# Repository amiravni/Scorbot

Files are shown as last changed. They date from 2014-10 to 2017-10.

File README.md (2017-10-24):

This is my work of building a Scorbot ER-V Controller with an arduino MEGA and drivers.

The project description is here: http://whatimade.today/geekcon-xii-scorbot-learns-to-draw/

Files and Folders consist of:

scorbotCOMcontrol - Most updated code, can get 6 encoder values and moves towards them

python - Python code for drawing images with scorbot

files - Some modified files to use with the python code

Eagle - Arduino mega shield design for scorbot

scorbotShieldTest - Shield Test...

Pins - Scorbot 50 Pins Data

ER3-Manual - Scorbot Manual

scorbotOldTestCode - My early work on scorbot, described here: http://www.whatimade.today/my-name-is-scorbot/

* Encoder_Scorbot - CPP code for encoders, taken and modified from  https://github.com/frodofski/Encoder_Polling_V2

* ScorbotCmd - The final code for controlling the Scorbot (Under Construction)

* ScorbotTest - Test code for Motors, Encoders and MicroSwitches

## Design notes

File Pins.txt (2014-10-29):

#/PIN/MOTOR

1,P0,2,         ,,,             34,P0,G
2,P0,1,         18,P0,5,        35,P0,4
3,P1,5,         19,P1,G,        36,P0,3
4,P1,3,         20,P1,4,        37,,
5,P1,1,         21,P1,2,        38,,
6,MS,5,         22,MS,G(NO),    39,,
7,MS,2,         23,MS,1,        40,,
8,MS,4,         24,MS,3,        41,,
9,LED,5,        25,LED,G,       42,,
10,LED,3,       26,LED,4,       43,,
11,LED,1,       27,LED,2,       44,,
12,M2,G,        28,GND,G,       45,M1,G
13,M2,5,        29,GND,5,       46,M1,5
14,M2,4,        30,GND,4,       47,M1,4
15,M2,3,        31,GND,3,       48,M1,3
16,M2,2,        32,GND,2,       49,M1,2
17,M2,1,        33,GND,1,       50,M1,1

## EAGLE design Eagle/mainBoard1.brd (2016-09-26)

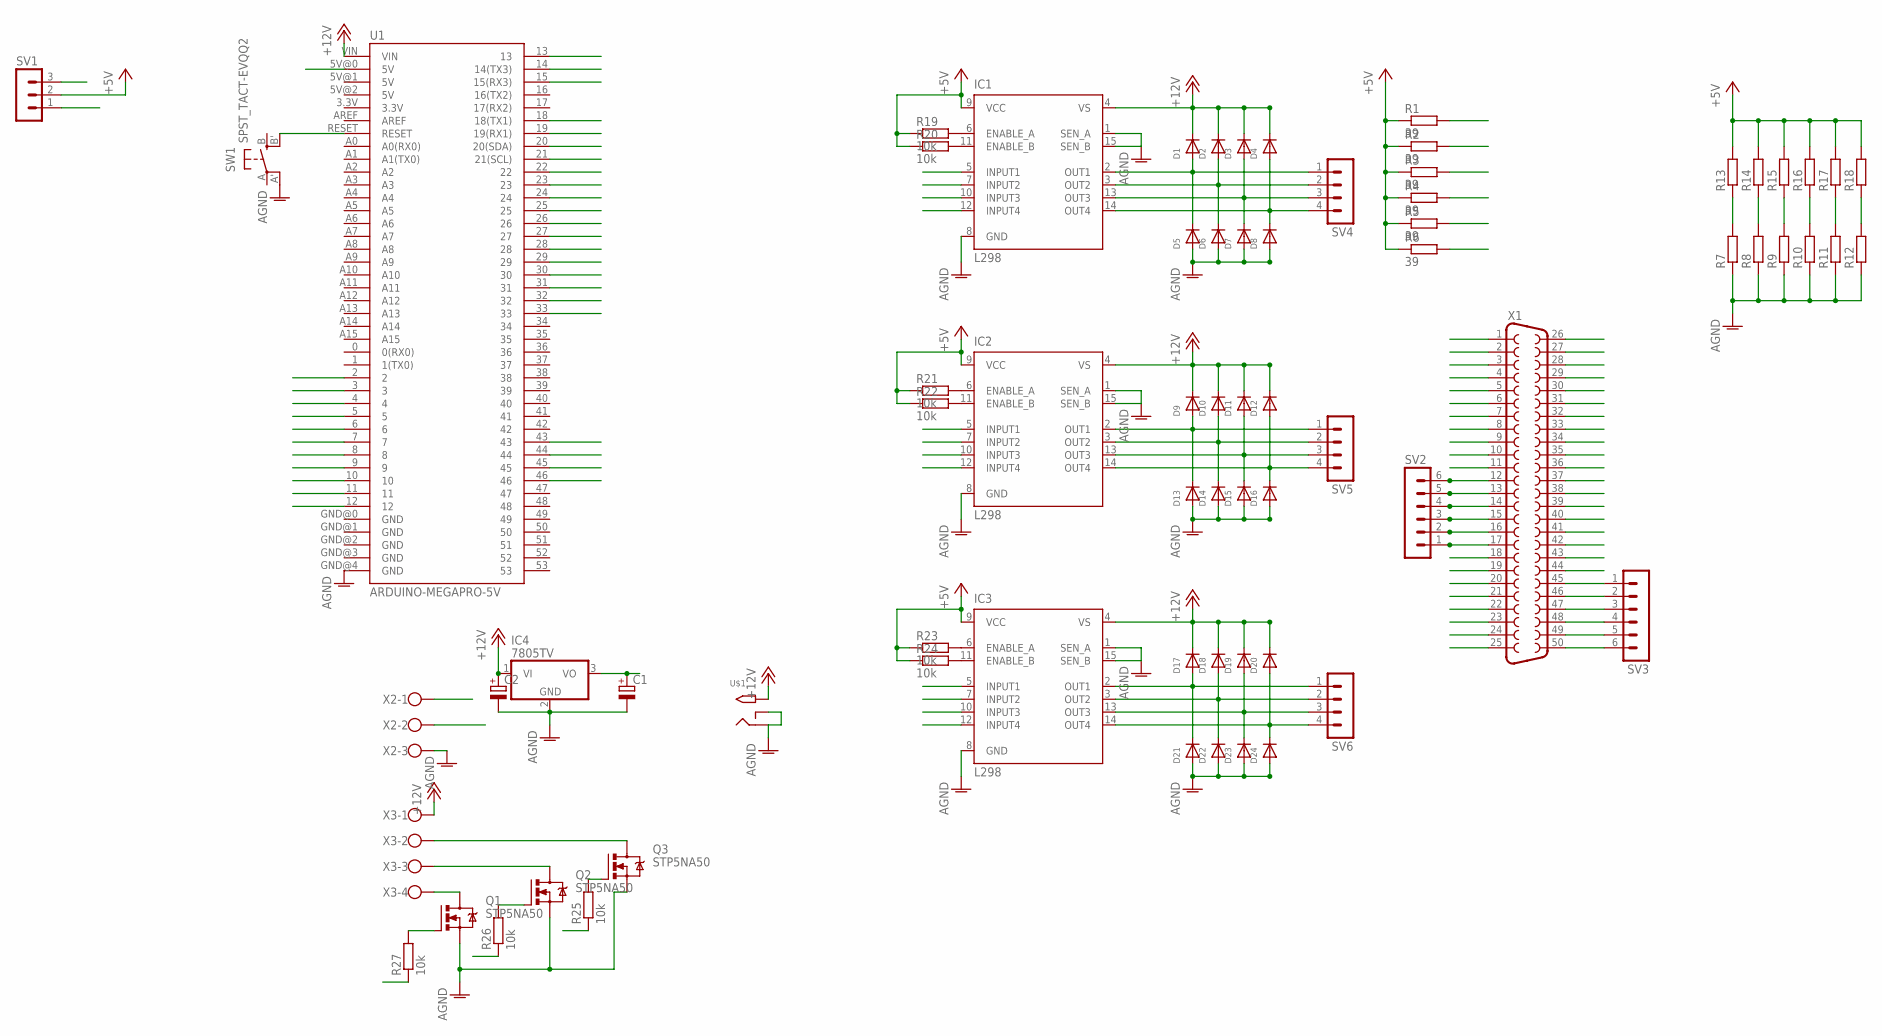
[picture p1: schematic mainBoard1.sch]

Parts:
C1, C2: CPOL-EUE2,5-6E; E2,5-6E
D1, D2, D3, D4, D5, D6, D7, D8, D9, D10, D11, D12, D13, D14, D15, D16, D17, D18, D19, D20, D21, D22, D23, D24: DIODESOD-323F; SOD-323F
IC1, IC2, IC3: L298; MULTIWATT-15
IC4: 7805TV; TO220V
Q1, Q2, Q3: STP5NA50; TO220BV
R1, R2, R3, R4, R5, R6: 39; 0207/10
R7, R8, R9, R10, R11, R12, R13, R14, R15, R16, R17, R18: R0207/10; 0207/10
R19, R20, R21, R22, R23, R24, R25, R26, R27: 10k; R0805
SV1: MA03-1
SV2, SV3: MA06-1
SV4, SV5, SV6: MA04-1
SW1: SPST_TACT-EVQQ2; EVQ-Q2
U1: ARDUINO-MEGAPRO-5V; ARDUINO_MEGA-PRO-5V
U$1: 2.1MMJACKTHM; PJ-102A
X1: F50VP
X2: W237-103
X3: W237-4

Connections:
5V_ARD: SV1.3, U1.5V@0 (5V)
5V_REG: C1.+, IC4.3 (VO), SV1.1, X2.1
+5V: IC1.9 (VCC), IC2.9 (VCC), IC3.9 (VCC), R1.1, R2.1, R3.1, R4.1, R5.1, R6.1, R13.2, R14.2, R15.2, R16.2, R17.2, R18.2, R19.1, R20.1, R21.1, R22.1, R23.1, R24.1, SV1.2
+12V: C2.+, D1.C, D2.C, D3.C, D4.C, D9.C, D10.C, D11.C, D12.C, D17.C, D18.C, D19.C, D20.C, IC1.4 (VS), IC2.4 (VS), IC3.4 (VS), IC4.1 (VI), U1.VIN, U$1.TIP, X3.1
AGND: C1.-, C2.-, D5.A, D6.A, D7.A, D8.A, D13.A, D14.A, D15.A, D16.A, D21.A, D22.A, D23.A, D24.A, IC1.1 (SEN_A), IC1.8 (GND), IC1.15 (SEN_B), IC2.1 (SEN_A), IC2.8 (GND), IC2.15 (SEN_B), IC3.1 (SEN_A), IC3.8 (GND), IC3.15 (SEN_B), IC4.2 (GND), Q1.S, Q2.S, Q3.S, R7.1, R8.1, R9.1, R10.1, R11.1, R12.1, SW1.A' (P1), U1.GND@4 (GND), U$1.RING, U$1.RING_SW, X1.28, X1.29, X1.30, X1.31, X1.32, X1.33, X2.3
LED_0: R1.2, X1.11
LED_1: R2.2, X1.27
LED_2: R3.2, X1.10
LED_3: R4.2, X1.26
LED_4: R5.2, X1.9
LED_5: R6.2, X1.25
LED_B: R27.1, U1.46
LED_DATA: U1.43, X2.2
LED_G: R26.1, U1.45
LED_R: R25.1, U1.44
M1_0: D1.A, D5.C, IC1.2 (OUT1), SV3.6, SV4.1, X1.50
M1_0_IN: IC1.5 (INPUT1), U1.14 (14(TX3))
M1_1: D3.A, D7.C, IC1.13 (OUT3), SV3.5, SV4.3, X1.49
M1_1_IN: IC1.10 (INPUT3), U1.4
M1_2: D9.A, D13.C, IC2.2 (OUT1), SV3.4, SV5.1, X1.48
M1_2_IN: IC2.5 (INPUT1), U1.6
M1_3: D11.A, D15.C, IC2.13 (OUT3), SV3.3, SV5.3, X1.47
M1_3_IN: IC2.10 (INPUT3), U1.8
M1_4: D17.A, D21.C, IC3.2 (OUT1), SV3.2, SV6.1, X1.46
M1_4_IN: IC3.5 (INPUT1), U1.10
M1_5: D19.A, D23.C, IC3.13 (OUT3), SV3.1, SV6.3, X1.45
M1_5_IN: IC3.10 (INPUT3), U1.12
M2_0: D2.A, D6.C, IC1.3 (OUT2), SV2.1, SV4.2, X1.17
M2_0_IN: IC1.7 (INPUT2), U1.15 (15(RX3))
M2_1: D4.A, D8.C, IC1.14 (OUT4), SV2.2, SV4.4, X1.16
M2_1_IN: IC1.12 (INPUT4), U1.5
M2_2: D10.A, D14.C, IC2.3 (OUT2), SV2.3, SV5.2, X1.15
M2_2_IN: IC2.7 (INPUT2), U1.7
M2_3: D12.A, D16.C, IC2.14 (OUT4), SV2.4, SV5.4, X1.14
M2_3_IN: IC2.12 (INPUT4), U1.9
M2_4: D18.A, D22.C, IC3.3 (OUT2), SV2.5, SV6.2, X1.13
M2_4_IN: IC3.7 (INPUT2), U1.11
M2_5: D20.A, D24.C, IC3.14 (OUT4), SV2.6, SV6.4, X1.12
M2_5_IN: IC3.12 (INPUT4), U1.13
MS_0: R7.2, R13.1, U1.2, X1.23
MS_1: R8.2, R14.1, U1.3, X1.7
MS_2: R9.2, R15.1, U1.21 (21(SCL)), X1.24
MS_3: R10.2, R16.1, U1.20 (20(SDA)), X1.8
MS_4: R11.2, R17.1, U1.19 (19(RX1)), X1.6
MS_5: R12.2, R18.1, U1.18 (18(TX1)), X1.22
unnamed: Q1.D, X3.4
unnamed: Q3.D, X3.2
unnamed: Q2.D, X3.3
unnamed: IC1.6 (ENABLE_A), R19.2
unnamed: IC1.11 (ENABLE_B), R20.2
unnamed: Q3.G, R25.2
unnamed: Q2.G, R26.2
unnamed: Q1.G, R27.2
unnamed: IC2.6 (ENABLE_A), R21.2
unnamed: IC2.11 (ENABLE_B), R22.2
unnamed: IC3.6 (ENABLE_A), R23.2
unnamed: IC3.11 (ENABLE_B), R24.2
unnamed: SW1.B' (S1), U1.RESET
P0_0: U1.22, X1.2
P0_1: U1.24, X1.1
P0_2: U1.26, X1.36
P0_3: U1.28, X1.35
P0_4: U1.30, X1.18
P0_5: U1.32, X1.34
P1_0: U1.23, X1.5
P1_1: U1.25, X1.21
P1_2: U1.27, X1.4
P1_3: U1.29, X1.20
P1_4: U1.31, X1.3
P1_5: U1.33, X1.19

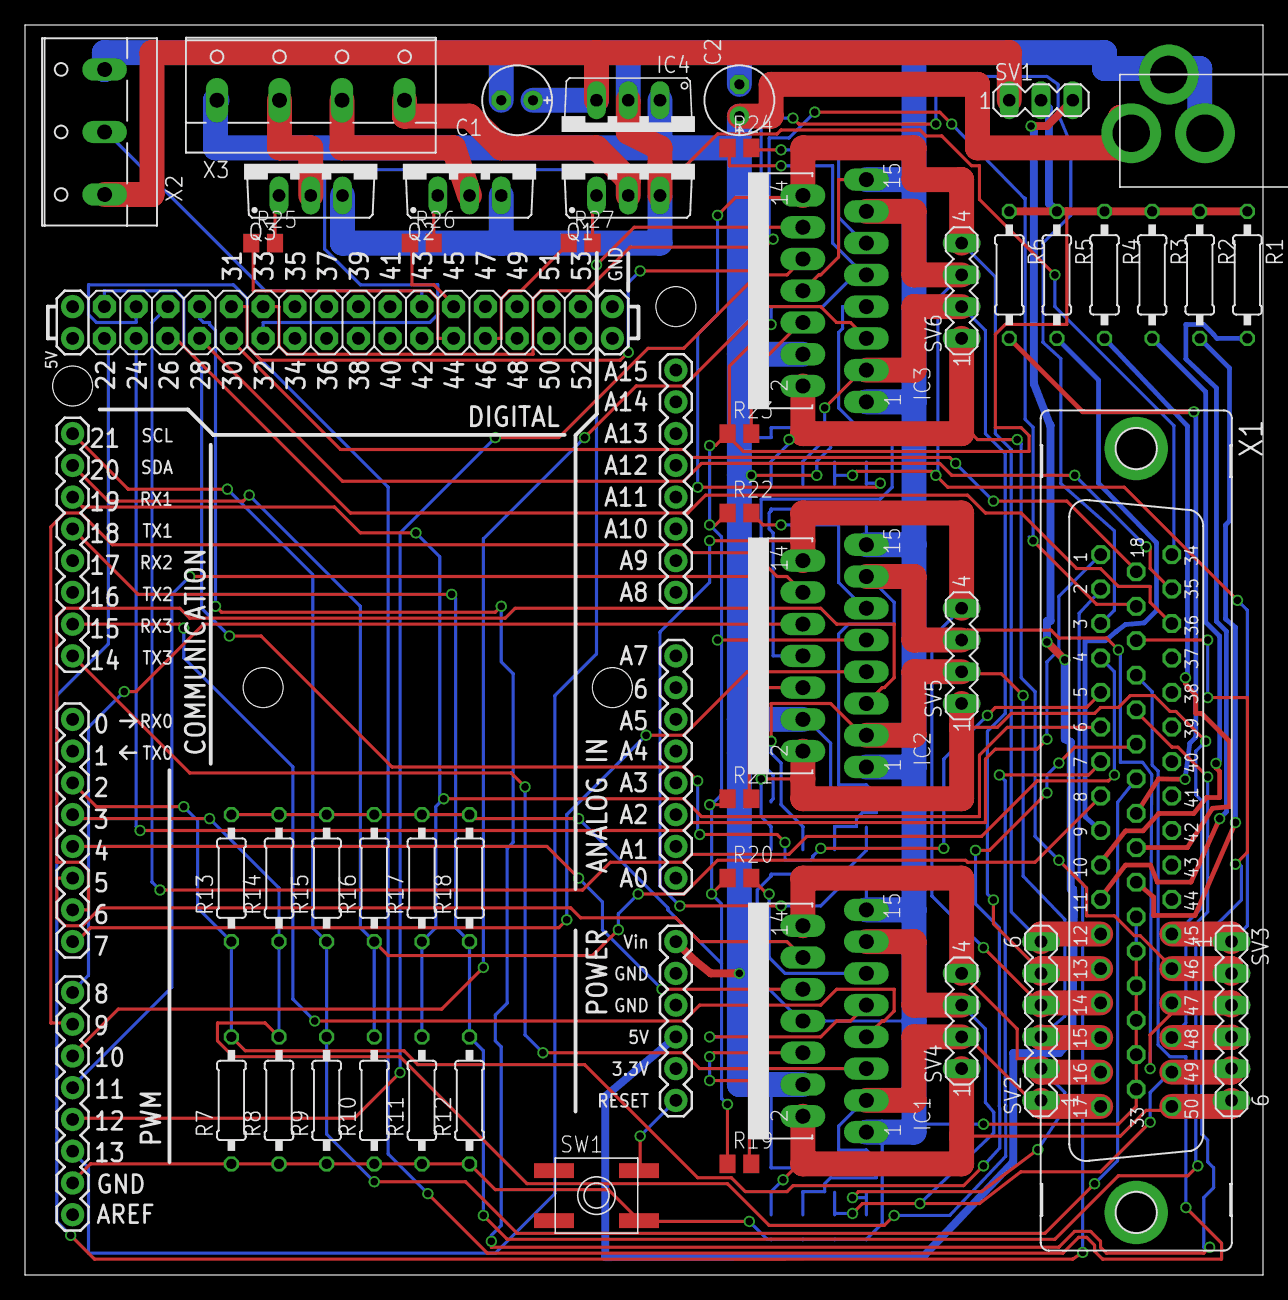
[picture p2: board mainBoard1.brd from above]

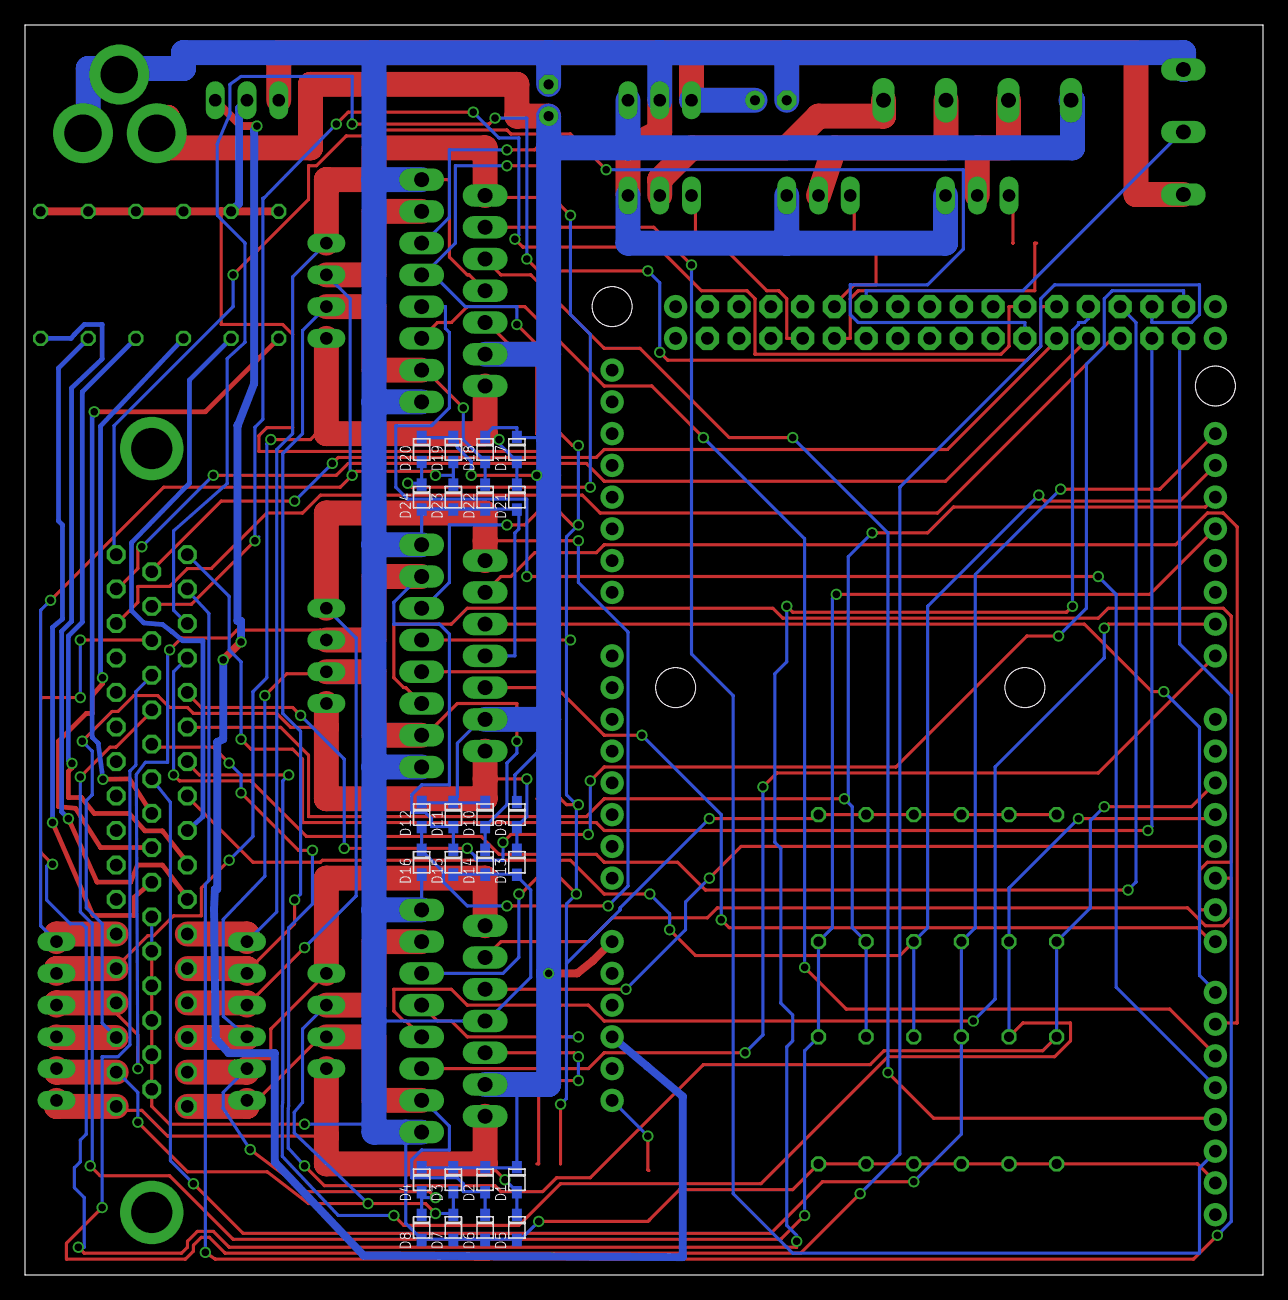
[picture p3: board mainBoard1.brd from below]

Board: 2 copper layers, 99.0 x 100.0 mm, 72 parts (24 on the bottom side), 70 nets.

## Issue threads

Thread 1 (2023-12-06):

comm control

ramonflores08, 2023-12-06:
Hello, I know this project was ages ago, but I was wondering if I could get some help getting my scorbot up and running. I will be getting the PCB next week, but I wanted to get a jump on the code. is there any way to get it to go to a certain coordinate just by communicating through serial instead of using the python scripts. I am terrible at python.

ramonflores08, 2023-12-06:
Lucky me I just got an email that the PCB will be here today. Way earlier than expected, but it will allow me more time to get this project up and running before the holidays.

I appreciate the reply and will do my best to do the conversion from Python to Arduino. I don't necessarily need XYZ coordinates though, so maybe I will just go with fixed coordinates for the time being.

My goal is to make this Scorbot into a bartender for the holidays.

ramonflores08, 2023-12-23:
https://github.com/amiravni/Scorbot/assets/7199615/a87f29c6-a5a7-44fb-8919-c1b9c3ae2dd2

I wanted to thank you for the amazing starting point and wanted to give you an update on my version in case you were interested. Maybe you still have that arm and want to give it some new life lol.

amiravni, 2023-12-29:
Thanks man! You just made my day with this video! When my kids grow up a bit more I'll go back to upgrade my project as well :)
I would be very happy to get the updated version and add it to the repository for everyone

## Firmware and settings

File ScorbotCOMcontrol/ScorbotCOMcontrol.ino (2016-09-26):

// NOTES:
// arm2 gets only negative values
// pitch gets only negative values

#define LEDPIN 49
#define TESTLED 1

#include "Encoder_Polling_V2.h"

#include <Adafruit_NeoPixel.h>
#ifdef __AVR__
  #include <avr/power.h>
#endif

#define PIN 43
Adafruit_NeoPixel strip = Adafruit_NeoPixel(55, PIN, NEO_GRB + NEO_KHZ800);

unsigned long timeStart;
volatile bool calibration = true;
// —————————————————————————  MicroSwitches
const int MS[6] = {
  2, 3, 21, 20, 19, 18
};
volatile boolean  MSpressed[6] = {
  0, 0, 0, 0, 0, 0
};
boolean initMTRCCW[6] = {false, false, true, false, true, true};

// —————————————————————————  Encoders
const int pin_P0[6] = {
  22, 24, 26, 28, 30, 32
};  // Encoder input pins
const int pin_P1[6] = {
  23, 25, 27, 29, 31, 33
};
int motors_current_state[6] = {
  0, 0, 0, 0, 0, 0
};
volatile short counter[6] = {
  0, 0, 0, 0, 0, 0
};
// —————————————————————————  Motors
//const int M1[6] = {
//  14,4,6,8,10,12};
//const int M2[6] = {
//  15,5,7,9,11,13};
const int M2[6] = {14, 4, 44, 8, 11, 12};
const int M1[6] = {15, 5, 7, 9, 10, 13};

const byte  headerChars[3] = {255, 254, 100};
const byte  headerInitChars[3] = {255, 254, 200};
const byte  headerPolyChars[3] = {255, 254, 150};
byte header[3] = {0, 0, 0};
short encoder_positions[6] = {0 , 0, 0, 0, 0, 0};
byte* encoder_position_ptr = (byte*)&encoder_positions;
short init_positions[6] = {0 , 0, 0, 0, 0, 0};
byte* init_position_ptr = (byte*)&init_positions;
short poly_positions[37];
byte* poly_position_ptr = (byte*)&poly_positions;
const int numOfCommandsPoly = 100;
int ptr = 0;

// ————————————————————————— Setup
void setup() {
  Serial.begin(9600);
  strip.begin();
  strip.show(); // Initialize all pixels to 'off'
  encoder_begin();  // Start the library
  for (int i = 0; i < 6; i++) {
    attach_encoder(i, pin_P0[i], pin_P1[i]);  // Attach an encoder to pins A and B
    pinMode(pin_P0[i], INPUT_PULLUP);
    pinMode(pin_P1[i], INPUT_PULLUP);
    pinMode(M1[i], OUTPUT);
    pinMode(M2[i], OUTPUT);
    motorST(M1[i], M2[i]);
    pinMode(MS[i], INPUT);
  }
  for (int i = 0; i < 5; i++) {
    Serial.print(MSpressed[i]);
  }
  Serial.println(MSpressed[6]);
  for (int iii = 0; iii < 37; iii++) {
    poly_positions[iii] = 0;
  }
  attachInterrupt(0, resetCounter0, FALLING);
  attachInterrupt(1, resetCounter1, FALLING);
  attachInterrupt(2, resetCounter2, FALLING);
  attachInterrupt(3, resetCounter3, FALLING);
  attachInterrupt(4, resetCounter4, FALLING);
  //attachInterrupt(5, resetCounter5, FALLING);
  pinMode(LEDPIN, OUTPUT);

  for (int i = 0; i < 5; i++) {
    Serial.print(MSpressed[i]);
  }
  Serial.println(MSpressed[6]);
 //rainbow(20);

  /*
    for (int i = 0; i < 5; i++) {
    Serial.print(MSpressed[i]);
    }
    Serial.println("");

    Serial.println("Current Counter:");

    for (int i = 0; i < 6 - 1; i++) {
    Serial.print(counter[i]);
    Serial.print("  ,  ");
    }
    Serial.println(counter[5]);

    Serial.println("Future Counter:");

    for (int i = 0; i < 6 - 1; i++) {
    Serial.print(encoder_positions[i]);
    Serial.print("  ,  ");
    }
    Serial.println(encoder_positions[5]);
  */
}

// ————————————————————————— MAIN



void loop() {
  short dir0[6] = {
    0, 0, 0, 0, 0, 0
  };
  ptr = 0;
  int point_or_poly = -1;
  bool print_encoders = 0;

  /// Serial read
  while (Serial.available() > 0)
  {
    header[0] = (byte)Serial.read();
    if (header[0] != headerChars[0]) {
      Serial.println("break0!");      
      break;
    }
    while (Serial.available() <= 0) {}
    header[1] =  (byte)Serial.read();
    if (header[1] != headerChars[1]) {
      Serial.println("break1!");      
      break;
    }

    while (Serial.available() <= 0) {}
    header[2] =  (byte)Serial.read();
    if (header[2] != headerChars[2] && header[2] != headerInitChars[2] && header[2] != headerPolyChars[2]) {
      Serial.println("break2!");
      break;
    }
    Serial.println("PASS!");
    if (header[2] == headerChars[2]) {
      point_or_poly = 0;
      while (ptr < 6 * sizeof(short)) {
        while (Serial.available() <= 0) {}
        encoder_position_ptr[ptr++] = (byte)Serial.read();  // ptr to byte array of 12, and then we get 6 shorts
      }

      if (encoder_positions[3] != encoder_positions[4]) {
        encoder_positions[4] = encoder_positions[3];
      }
      Serial.print("Srl: ");
      for (int i = 0; i < 5; i++) {
        Serial.print(encoder_positions[i]);
        Serial.print("  ,  ");
      }
      Serial.println(encoder_positions[5]);
      print_encoders = 1;

    }
    if (header[2] == headerInitChars[2]) {
      while (ptr < 6 * sizeof(short)) {
        while (Serial.available() <= 0) {}
        init_position_ptr[ptr++] = (byte)Serial.read();  // ptr to byte array of 12, and then we get 6 shorts
      }

      for ( int iii = 0; iii < 6 ; iii++) {
        if (init_positions[iii]) {
          initMTRCCW[iii] = true;
        }
        else {
          initMTRCCW[iii] = false;
        }
      }
      Serial.print("SrlHome: ");
      for (int i = 0; i < 5; i++) {
        encoder_positions[i] = 0;
        counter[i] = 0;
        Serial.print(init_positions[i]);
        Serial.print("  ,  ");
      }
      Serial.println(init_positions[5]);
      goHome();

      calibration = false;
    }
    if (header[2] == headerPolyChars[2]) {
      point_or_poly = 1;
      while (ptr < (6 * 6 + 1) * sizeof(short)) {
        while (Serial.available() <= 0) {}
        poly_position_ptr[ptr++] = (byte)Serial.read();  // ptr to byte array of 12, and then we get 6 shorts
        //Serial.print((int)poly_position_ptr[ptr - 1]);
        //Serial.print(",");
      }
      Serial.print("SrlPoly: ");
      for (int i = 0; i < 36; i++) {
        Serial.print(poly_position_ptr[i]);
        Serial.print("  ,  ");
      }
      Serial.println(poly_position_ptr[36]);
    }
  }

  int numOfCommands = 1;
  float dT = 0;
  if (point_or_poly == 1) {
    numOfCommands = numOfCommandsPoly;
    dT =  (float)poly_positions[36] / (float)numOfCommands;
    Serial.print("Srldt: ");
    Serial.println(dT);
  }
  if (point_or_poly == 0) numOfCommands = 1;


  for (int nnn = 0; nnn < numOfCommands; nnn++) {
    if (point_or_poly == 1) {
      for (int e = 0; e < 3; e++) {
        float newTime = dT * (float)nnn;
        float encoderTmp = 0;
        encoder_positions[e] = 0;
        for (int p = 0; p < 5; p++) {
          //encoder_positions[e] = (encoder_positions[e] + poly_position[ e*6 + p]/10 ) * newTime;
          encoderTmp = (encoderTmp + (float)poly_positions[ e * 6 + p] / 10.0 ) * newTime;
        }
        encoder_positions[e] = (short)floor(encoderTmp + (float)poly_positions[ e * 6 + 5] / 10.0);
      }
    }

    bool finish_movement_flag = 0;
    timeStart = millis();
    while (!finish_movement_flag) {

      /// arms 0-4 control
      finish_movement_flag = 1;
      for (int i = 0; i < 3; i++) {
        if ( abs(counter[i] - encoder_positions[i]) > 1 ) {

          finish_movement_flag = 0;
          if (counter[i] < encoder_positions[i])  {
            if (motors_current_state[i] != 1) {
              motorFW(M1[i], M2[i]);
              motors_current_state[i] = 1;
            }
          }
          else {
            if (motors_current_state[i] != -1) {
              motorBW(M1[i], M2[i]);
              motors_current_state[i] = -1;
            }
          }
        }
        else {
          if (motors_current_state[i] != 0) {
            motorST(M1[i], M2[i]);
            motors_current_state[i] = 0;
          }
        }

        /// Encoder read
        dir0[i] = encoder_data(i);  // First
        if (dir0[i] != 0) // Check for rotation
        {
          counter[i] += dir0[i];
        }

      }

      /// gripper pitch
      int i = 3;
      if ( abs(counter[i] - encoder_positions[i]) > 5 ) {

        finish_movement_flag = 0;
        if (counter[i] < encoder_positions[i])  {
          if (motors_current_state[i] != 1) {
            motorFW(M1[i], M2[i]);
            motorFW(M1[i + 1], M2[i + 1]);
            motors_current_state[i] = 1;
          }
        }
        else {
          if (motors_current_state[i] != -1) {
            motorBW(M1[i], M2[i]);
            motorBW(M1[i + 1], M2[i + 1]);
            motors_current_state[i] = -1;
          }
        }
      }
      else {
        if (motors_current_state[i] != 0) {
          motorST(M1[i], M2[i]);
          motorST(M1[i + 1], M2[i + 1]);
          motors_current_state[i] = 0;
        }
      }

      /// Encoder read
      dir0[i] = encoder_data(i);  // First
      if (dir0[i] != 0) // Check for rotation
      {
        counter[i] += dir0[i];
      }

      /// Gripper control
      if ( abs(counter[5] - encoder_positions[5]) > 5 ) {
        finish_movement_flag = 0;
        if (millis() -  timeStart <  abs(encoder_positions[5])) {
          if (counter[5] < encoder_positions[5])  {
            if (motors_current_state[5] != 1) {
              motorFW(M1[5], M2[5]);
              motors_current_state[5] = 1;
            }
          }
          else {
            if (motors_current_state[5] != -1) {
              motorBW(M1[5], M2[5]);
              motors_current_state[5] = -1;
            }
          }
        }
        else {
          if (motors_current_state[5] != 0) {
            motorST(M1[5], M2[5]);
            motors_current_state[5] = 0;
            counter[5] = encoder_positions[5];
          }
        }
      }
    }
  }
  /// print encoders
  if (print_encoders) {
    Serial.print("Enc: ");
    for (int i = 0; i < 5; i++) {
      Serial.print(counter[i]);
      Serial.print("  ,  ");
    }
    Serial.println(counter[5]);
  }

}


void motorFW(const int mtr1, const int mtr2  ) {
  digitalWrite(mtr1, HIGH);
  digitalWrite(mtr2, LOW);
}
void motorBW(const int mtr1, const int mtr2  ) {
  digitalWrite(mtr2, HIGH);
  digitalWrite(mtr1, LOW);
}
void motorST(const int mtr1, const int mtr2  ) {
  digitalWrite(mtr1, LOW);
  digitalWrite(mtr2, LOW);
}

void resetCounter0() {
  if (calibration)  counter[0] = 0;
  MSpressed[0] = 1;
  if (TESTLED) {
    if (digitalRead(LEDPIN)) digitalWrite(LEDPIN, LOW);
    else digitalWrite(LEDPIN, HIGH);
  }
}
void resetCounter1() {
  if (calibration)  counter[1] = 0;
  MSpressed[1] = 1;
  if (TESTLED) {
    if (digitalRead(LEDPIN)) digitalWrite(LEDPIN, LOW);
    else digitalWrite(LEDPIN, HIGH);
  }
}
void resetCounter2() {
  if (calibration)  counter[2] = 0;
  MSpressed[2] = 1;
  if (TESTLED) {
    if (digitalRead(LEDPIN)) digitalWrite(LEDPIN, LOW);
    else digitalWrite(LEDPIN, HIGH);
  }
}
void resetCounter3() {
  if (calibration) counter[3] = 0;
  if (calibration) counter[4] = 0;  // We obly use pitch and not roll
  MSpressed[3] = 1;
  if (TESTLED) {
    if (digitalRead(LEDPIN)) digitalWrite(LEDPIN, LOW);
    else digitalWrite(LEDPIN, HIGH);
  }
}
void resetCounter4() {
  //counter[4] = 0;
  MSpressed[4] = 1;
  if (TESTLED) {
    if (digitalRead(LEDPIN)) digitalWrite(LEDPIN, LOW);
    else digitalWrite(LEDPIN, HIGH);
  }
}
void resetCounter5() {
  if (calibration) counter[5] = 0;
  MSpressed[5] = 1;
  if (0) {
    if (digitalRead(LEDPIN)) digitalWrite(LEDPIN, LOW);
    else digitalWrite(LEDPIN, HIGH);
  }
}


void goHome() {
  // —————— Init Motors 2
  for (int i = 2; i < 3; i++) {
    Serial.print("Init Motor #");
    Serial.println(i);
    if (digitalRead(MS[i])) {
      boolean FWdir = initMTRCCW[i];
      if (FWdir)
        motorFW(M1[i], M2[i]);
      else
        motorBW(M1[i], M2[i]);
      MSpressed[i] = false;
      while ( !MSpressed[i] );
      motorST(M1[i], M2[i]);
    }
  }

  // —————— Init Motors 0,1,2
  for (int i = 0; i < 3; i++) {
    Serial.print("Init Motor #");
    Serial.println(i);
    if (digitalRead(MS[i])) {
      boolean FWdir = initMTRCCW[i];
      if (FWdir)
        motorFW(M1[i], M2[i]);
      else
        motorBW(M1[i], M2[i]);
      MSpressed[i] = false;
      while ( !MSpressed[i] );
      motorST(M1[i], M2[i]);
    }
  }

  Serial.println("Init Motor #3+#4 (1)");
  int i = 3;
  if (digitalRead(MS[i])) {
    boolean FWdir = initMTRCCW[i];
    if (FWdir) {
      motorFW(M1[i], M2[i]);
      motorFW(M1[i + 1], M2[i + 1]);
    }
    else
    {
      motorBW(M1[i], M2[i]);
      motorBW(M1[i + 1], M2[i + 1]);
    }
    MSpressed[i] = false;
    while ( !MSpressed[i] );
    motorST(M1[i], M2[i]);
    motorST(M1[i + 1], M2[i + 1]);
  }

/*
  Serial.println("Init Motor #3+#4 (2)");
  if (digitalRead(MS[i + 1])) {
    boolean FWdir = initMTRCCW[i + 1];
    if (FWdir) {
      motorFW(M1[i], M2[i]);
      motorBW(M1[i + 1], M2[i + 1]);
    }
    else
    {
      motorBW(M1[i], M2[i]);
      motorFW(M1[i + 1], M2[i + 1]);
    }
    MSpressed[i + 1] = false;
    while ( !MSpressed[i + 1] );
    motorST(M1[i], M2[i]);
    motorST(M1[i + 1], M2[i + 1]);
  }
*/
  Serial.println("Init DONE!");
}

// Fill the dots one after the other with a color
void colorWipe(uint32_t c, uint8_t wait) {
  for(uint16_t i=0; i<strip.numPixels(); i++) {
    strip.setPixelColor(i, c);
    strip.show();
    delay(wait);
  }
}

void rainbow(uint8_t wait) {
  uint16_t i, j;

  for(j=0; j<256; j++) {
    for(i=0; i<strip.numPixels(); i++) {
      strip.setPixelColor(i, Wheel((i+j) & 255));
    }
    strip.show();
    delay(wait);
  }
}

// Slightly different, this makes the rainbow equally distributed throughout
void rainbowCycle(uint8_t wait) {
  uint16_t i, j;

  for(j=0; j<256*5; j++) { // 5 cycles of all colors on wheel
    for(i=0; i< strip.numPixels(); i++) {
      strip.setPixelColor(i, Wheel(((i * 256 / strip.numPixels()) + j) & 255));
    }
    strip.show();
    delay(wait);
  }
}

//Theatre-style crawling lights.
void theaterChase(uint32_t c, uint8_t wait) {
  for (int j=0; j<10; j++) {  //do 10 cycles of chasing
    for (int q=0; q < 3; q++) {
      for (int i=0; i < strip.numPixels(); i=i+3) {
        strip.setPixelColor(i+q, c);    //turn every third pixel on
      }
      strip.show();

      delay(wait);

      for (int i=0; i < strip.numPixels(); i=i+3) {
        strip.setPixelColor(i+q, 0);        //turn every third pixel off
      }
    }
  }
}

//Theatre-style crawling lights with rainbow effect
void theaterChaseRainbow(uint8_t wait) {
  for (int j=0; j < 256; j++) {     // cycle all 256 colors in the wheel
    for (int q=0; q < 3; q++) {
      for (int i=0; i < strip.numPixels(); i=i+3) {
        strip.setPixelColor(i+q, Wheel( (i+j) % 255));    //turn every third pixel on
      }
      strip.show();

      delay(wait);

      for (int i=0; i < strip.numPixels(); i=i+3) {
        strip.setPixelColor(i+q, 0);        //turn every third pixel off
      }
    }
  }
}

// Input a value 0 to 255 to get a color value.
// The colours are a transition r - g - b - back to r.
uint32_t Wheel(byte WheelPos) {
  WheelPos = 255 - WheelPos;
  if(WheelPos < 85) {
    return strip.Color(255 - WheelPos * 3, 0, WheelPos * 3);
  }
  if(WheelPos < 170) {
    WheelPos -= 85;
    return strip.Color(0, WheelPos * 3, 255 - WheelPos * 3);
  }
  WheelPos -= 170;
  return strip.Color(WheelPos * 3, 255 - WheelPos * 3, 0);
}

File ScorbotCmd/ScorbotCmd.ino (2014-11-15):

#define LEDPIN 13
#define TESTLED 1

#include "Encoder_Scorbot.h"

unsigned long startTime;
// —————————————————————————  MicroSwitches
const int MS[6] = {
  2,3,21,20,19,18};
volatile boolean  MSpressed[6]={
  0,0,0,0,0,0};    
boolean initMTRCCW[6] = {
  false, false, true,false,false,false};

// —————————————————————————  Encoders
const int pin_P0[6] = {
  22,24,26,28,30,32};  // Encoder input pins
const int pin_P1[6] = {
  23,25,27,29,31,33};
volatile long  counter[6]={
  0,0,0,0,0,0};
// —————————————————————————  Motors
const int M1[6] = {
  36,38,40,42,44,46};
const int M2[6] = {
  37,39,41,43,45,47};



// ————————————————————————— Setup
void setup() {
  Serial.begin(9600);
  encoder_begin();  // Start the library
  for (int i=0;i<6;i++) {
    attach_encoder(i, pin_P0[i], pin_P1[i]);  // Attach an encoder to pins A and B
    pinMode(pin_P0[i],INPUT_PULLUP);
    pinMode(pin_P1[i],INPUT_PULLUP);
    pinMode(M1[i],OUTPUT);
    pinMode(M2[i],OUTPUT);
    motorST(M1[i],M2[i]);
    pinMode(MS[i],INPUT);
  }
  attachInterrupt(0, resetCounter0, FALLING);  
  attachInterrupt(1, resetCounter1, FALLING);  
  attachInterrupt(2, resetCounter2, FALLING);  
  attachInterrupt(3, resetCounter3, FALLING);  
  attachInterrupt(4, resetCounter4, FALLING);  
  //attachInterrupt(5, resetCounter5, FALLING);    
  pinMode(LEDPIN,OUTPUT);

}

// ————————————————————————— MAIN
void loop() {
  char cmd=0;
  //  unsigned long testTime = 500;

  Serial.println("Hi I'm Scorbot! \t What would you like to do?");
  Serial.println("0 - Go Home ");
  Serial.println("1 - Control specific arm ");
  Serial.println("2 - Control all arms ");
  Serial.println("3 - Select Coordinates ");

  while  (Serial.available() == 0);
  cmd = Serial.read();
  switch (cmd) {
  case '0':
    initWrapper();
    break;
  case '1':
     controlOneArm();
    break;
  case '2':
    break;
  case '3':
    break ;  
  }

}
/*

 
 
 if ( millis() - startTime  < testTime  ) {
 for (int i=0;i<6;i++) {
 counter[i] = encoder_data(i);  // First 
 }
 
 }
 else
 { 
 for (int i=0;i<6;i++) {
 motorST(M1[i],M2[i]);
 }
 }
 
 
 
 
 if ( (millis() - startTime  > testTime + 50 ) && ( millis() - startTime< testTime + 55 ) ) { 
 for (int i=0;i<6-1;i++) {
 Serial.print(counter[i]);
 Serial.print("  ,  ");
 }
 Serial.println(counter[5]);
 }
 
 if (Serial.available() > 0) 
 {
 
 cmd = Serial.read();
 if (cmd=='q') {
 for (int i=5;i<6;i++) {
 motorFW(M1[i],M2[i]);
 }
 }
 else if (cmd == 'Q')  {
 for (int i=5;i<6;i++) {
 motorBW(M1[i],M2[i]);
 }
 }
 else if (cmd == 'a')  {
 int i=3;
 motorBW(M1[i],M2[i]);
 motorFW(M1[i+1],M2[i+1]);    
 }    
 else if (cmd == 'A')  {
 int i=3;
 motorFW(M1[i],M2[i]);
 motorBW(M1[i+1],M2[i+1]);         
 }
 startTime = millis();
 }
 */





void motorFW(const int mtr1, const int mtr2  ){
  digitalWrite(mtr1, HIGH);
  digitalWrite(mtr2, LOW);
}
void motorBW(const int mtr1, const int mtr2  ){
  digitalWrite(mtr2, HIGH);
  digitalWrite(mtr1, LOW);
}
void motorST(const int mtr1, const int mtr2  ){
  digitalWrite(mtr1, LOW);
  digitalWrite(mtr2, LOW);
}

void resetCounter0(){ 
  counter[0]=0;
  MSpressed[0]=1;
  if (TESTLED) {
    if (digitalRead(LEDPIN)) digitalWrite(LEDPIN,LOW);
    else digitalWrite(LEDPIN,HIGH);
  }
}
void resetCounter1(){  
  counter[1]=0;
  MSpressed[1]=1;
  if (TESTLED) {
    if (digitalRead(LEDPIN)) digitalWrite(LEDPIN,LOW);
    else digitalWrite(LEDPIN,HIGH);
  }
}
void resetCounter2(){  
  counter[2]=0;
  MSpressed[2]=1;
  if (TESTLED) {
    if (digitalRead(LEDPIN)) digitalWrite(LEDPIN,LOW);
    else digitalWrite(LEDPIN,HIGH);
  }
}
void resetCounter3(){  
  counter[3]=0;
  MSpressed[3]=1;
  if (TESTLED) {
    if (digitalRead(LEDPIN)) digitalWrite(LEDPIN,LOW);
    else digitalWrite(LEDPIN,HIGH);
  }
}
void resetCounter4(){  
  counter[4]=0;
  MSpressed[4]=1;
  if (TESTLED) {
    if (digitalRead(LEDPIN)) digitalWrite(LEDPIN,LOW);
    else digitalWrite(LEDPIN,HIGH);
  }
}
void resetCounter5(){  
  counter[5]=0;
  MSpressed[5]=1;
  if (0) {
    if (digitalRead(LEDPIN)) digitalWrite(LEDPIN,LOW);
    else digitalWrite(LEDPIN,HIGH);
  }
}


int init(boolean initMTRCCW[6] ) {


  // —————— Init Motors 0,1,2
  for (int i=0;i<3;i++) {   
    Serial.print("Init Motor #");
    Serial.println(i);
    if (digitalRead(MS[i])) {
      boolean FWdir = initMTRCCW[i];
      if (FWdir)
        motorFW(M1[i],M2[i]);
      else
        motorBW(M1[i],M2[i]);
      MSpressed[i]=false;
      while ( !MSpressed[i] )  {
        if (Serial.available() > 0)  return 0;
      }; 
      motorST(M1[i],M2[i]);
    }
    else {
      Serial.println("MS is pressed");
   }
  }
  Serial.println("Init Motor #3+#4 (1)");
  int i=3;
  if (digitalRead(MS[i])) {
    boolean FWdir = initMTRCCW[i];
    if (FWdir) {
      motorFW(M1[i],M2[i]);
      motorBW(M1[i+1],M2[i+1]);
    }
    else
    {
      motorBW(M1[i],M2[i]);
      motorFW(M1[i+1],M2[i+1]);
    }
    MSpressed[i]=false;
    while ( !MSpressed[i] )        if (Serial.available() > 0)  return 0; 
    motorST(M1[i],M2[i]);
    motorST(M1[i+1],M2[i+1]);
  }
      else {
      Serial.println("MS is pressed");
   }

  Serial.println("Init Motor #3+#4 (2)");
  if (digitalRead(MS[i+1])) {
    boolean FWdir = initMTRCCW[i+1];
    if (FWdir) {
      motorFW(M1[i],M2[i]);
      motorFW(M1[i+1],M2[i+1]);
    }
    else
    {
      motorBW(M1[i],M2[i]);
      motorBW(M1[i+1],M2[i+1]);
    }
    MSpressed[i+1]=false;
    while ( !MSpressed[i+1] )        if (Serial.available() > 0)  return 0;
    motorST(M1[i],M2[i]);
    motorST(M1[i+1],M2[i+1]);
  }  
      else {
      Serial.println("MS is pressed");
   }

  i=5;
  Serial.println("Init GRIPPER");
  boolean FWdir = initMTRCCW[i];
  if (FWdir)
    motorFW(M1[i],M2[i]);
  else
    motorBW(M1[i],M2[i]);
  for (int t=0;t<10;t++) {
    if (Serial.available() > 0)  return 0;
    delay(100); 
  }
  motorST(M1[i],M2[i]);

  return 1;
}

void initWrapper()
{
  boolean initFlag=false;
  while(!initFlag) {  
    initFlag=true;
    Serial.println("select directions of motors 0 , 2 , 5 (example: 011)");
    Serial.println("Motor0 (0-CW , 1-CCW)");
    Serial.println("Motor2 (0-Down , 1-Up)");
    Serial.println("Motor5 (0-Open , 1-Close)");  
    int initMotors[3] ={
      0,2,5        };

    for (int i=0;i<3;i++) {
      while  (Serial.available() == 0);
      char dir = Serial.read();
      if (dir== '0' ) initMTRCCW[initMotors[i]] = false;
      else if (dir == '1' ) initMTRCCW[initMotors[i]] = true;
      else  {
        Serial.println("ERROR! Try Again!");
        initFlag=false;
        cleanSerial();
        break;  
      }
    }
  }
  if (init(initMTRCCW ))   Serial.println("Init DONE!"); 
  else   {
    Serial.println("Init FAIL!!"); 
   cleanSerial();
  } 

}
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

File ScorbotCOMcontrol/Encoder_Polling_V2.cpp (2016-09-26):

/******************************************************************************************
 * Rotary-encoder decoder for Arduino
 ******************************************************************************************
 * Copyright (c) Robert Bakker 2013
 *
 * This file is free software; you can redistribute it and/or modify
 * it under the terms of either the GNU General Public License version 2
 * or the GNU Lesser General Public License version 2.1, both as
 * published by the Free Software Foundation.
 ******************************************************************************************
 * This library handles polling and decoding of up to 5 rotary encoders.
 * It is non-blocking code that executes in the background while your sketch
 * does it's thing.
 *****************************************************************************************/

#include "Encoder_Polling_V2.h"
#include "Arduino.h"	// Has just about everything in it


/*Private #defines************************************************************************/

// Used by state machines
#define STANDBY 0
#define WAITING 1
#define IDLE 2


/*Functions Prototypes********************************************************************/

inline void encoder0_demod(void);
inline void encoder1_demod(void);
inline void encoder2_demod(void);
inline void encoder3_demod(void);
inline void encoder4_demod(void);


/*Declare Variables***********************************************************************/

struct encoderVars
{
	volatile uint8_t state;

	volatile uint8_t pin_A;
	volatile uint8_t pin_B;

	volatile int8_t data;

	volatile uint8_t pinState_A;
	volatile uint8_t pinStateOld_A;
	volatile uint8_t pinState_B;

	volatile uint8_t enable;
};

// Initialize variables (start all state machines in STANDBY state)
struct encoderVars encoder0 = { STANDBY, 0, 0, 0, 0, 0, 0, 0 };
struct encoderVars encoder1 = { STANDBY, 0, 0, 0, 0, 0, 0, 0 };
struct encoderVars encoder2 = { STANDBY, 0, 0, 0, 0, 0, 0, 0 };
struct encoderVars encoder3 = { STANDBY, 0, 0, 0, 0, 0, 0, 0 };
struct encoderVars encoder4 = { STANDBY, 0, 0, 0, 0, 0, 0, 0 };


/*Start of Functions**********************************************************************/

// This function sets up timer2 to trigger an ISR every 300 us.
void encoder_begin(void)
{
	cli();					// Disable global interrupts

	TCCR2A = 0;				// Clear timer2's control registers
	TCCR2B = 0;
	TIMSK2 = 0;				// ...and interrupt mask register (just in case)
	TCNT2 = 0;				// Pre-load the timer to 0
	OCR2A = 149;			// Set output compare register to 149
	TCCR2A |= _BV(WGM21);	// Turn on CTC mode (Clear Timer on Compare match)
	TCCR2B |= 0b010;		// Set prescaler to 1 (starts timer) 
	TIMSK2 |= _BV(OCIE2A);	// Enable timer compare interrupt 

	sei();					// Re-enable global interrupts
}


void attach_encoder(uint8_t _encNum, uint8_t _pin_A, uint8_t _pin_B)
{
	switch(_encNum)
	{
		case 0:
			encoder0.pin_A = _pin_A;
			encoder0.pin_B = _pin_B;

			pinMode(encoder0.pin_A, INPUT);
			pinMode(encoder0.pin_B, INPUT);

			encoder0.enable = 1;
			break;

		case 1:
			encoder1.pin_A = _pin_A;
			encoder1.pin_B = _pin_B;

			pinMode(encoder1.pin_A, INPUT);
			pinMode(encoder1.pin_B, INPUT);

			encoder1.enable = 1;
			break;

		case 2:
			encoder2.pin_A = _pin_A;
			encoder2.pin_B = _pin_B;

			pinMode(encoder2.pin_A, INPUT);
			pinMode(encoder2.pin_B, INPUT);

			encoder2.enable = 1;
			break;

		case 3:
			encoder3.pin_A = _pin_A;
			encoder3.pin_B = _pin_B;

			pinMode(encoder3.pin_A, INPUT);
			pinMode(encoder3.pin_B, INPUT);

			encoder3.enable = 1;
			break;

		case 4:
			encoder4.pin_A = _pin_A;
			encoder4.pin_B = _pin_B;

			pinMode(encoder4.pin_A, INPUT);
			pinMode(encoder4.pin_B, INPUT);

			encoder4.enable = 1;
			break;
	}
}


void dettach_encoder(uint8_t _encNum)
{
	switch(_encNum)
	{
		case 0:
			encoder0.enable = 0;
			encoder0.state = STANDBY;
			break;

		case 1:
			encoder1.enable = 0;
			encoder1.state = STANDBY;
			break;

		case 2:
			encoder2.enable = 0;
			encoder2.state = STANDBY;
			break;

		case 3:
			encoder3.enable = 0;
			encoder3.state = STANDBY;
			break;

		case 4:
			encoder4.enable = 0;
			encoder4.state = STANDBY;
			break;
	}
}


int8_t encoder_data(uint8_t _encNum)
{
	switch(_encNum)
	{
		case 0:
			if(encoder0.state == IDLE)
			{
				int8_t temp = encoder0.data;
				encoder0.state = STANDBY;
				return temp;
			}

			else
				return 0;

			break;

		case 1:
			if(encoder1.state == IDLE)
			{
				int8_t temp = encoder1.data;
				encoder1.state = STANDBY;
				return temp;
			}

			else
				return 0;

			break;

		case 2:
			if(encoder2.state == IDLE)
			{
				int8_t temp = encoder2.data;
				encoder2.state = STANDBY;
				return temp;
			}

			else
				return 0;

			break;

		case 3:
			if(encoder3.state == IDLE)
			{
				int8_t temp = encoder3.data;
				encoder3.state = STANDBY;
				return temp;
			}

			else
				return 0;

			break;

		case 4:
			if(encoder4.state == IDLE)
			{
				int8_t temp = encoder0.data;
				encoder4.state = STANDBY;
				return temp;
			}

			else
				return 0;

			break;
	}
}


/*ISR*************************************************************************************/

ISR(TIMER2_COMPA_vect)
{
	if(encoder0.enable)
		encoder0_demod();

	if(encoder1.enable)
		encoder1_demod();

	if(encoder2.enable)
		encoder2_demod();

	if(encoder3.enable)
		encoder3_demod();

	if(encoder4.enable)
		encoder4_demod();
}


inline void encoder0_demod(void)
{
	switch(encoder0.state)
	{
		case STANDBY:
			encoder0.pinStateOld_A = digitalRead(encoder0.pin_A);
			encoder0.state = WAITING;
			break;

		case WAITING:
			encoder0.pinState_A = digitalRead(encoder0.pin_A);
			if(encoder0.pinState_A != encoder0.pinStateOld_A)
			{
				encoder0.pinState_B = digitalRead(encoder0.pin_B);
				if(encoder0.pinState_A == encoder0.pinState_B)
					encoder0.data = 1;

				else
					encoder0.data = -1;

				encoder0.state = IDLE;
			}
			break;
	}
}

inline void encoder1_demod(void)
{
	switch(encoder1.state)
	{
		case STANDBY:
			encoder1.pinStateOld_A = digitalRead(encoder1.pin_A);
			encoder1.state = WAITING;
			break;

		case WAITING:
			encoder1.pinState_A = digitalRead(encoder1.pin_A);
			if(encoder1.pinState_A != encoder1.pinStateOld_A)
			{
				encoder1.pinState_B = digitalRead(encoder1.pin_B);
				if(encoder1.pinState_A == encoder1.pinState_B)
					encoder1.data = 1;

				else
					encoder1.data = -1;

				encoder1.state = IDLE;
			}
			break;
	}
}

inline void encoder2_demod(void)
{
	switch(encoder2.state)
	{
		case STANDBY:
			encoder2.pinStateOld_A = digitalRead(encoder2.pin_A);
			encoder2.state = WAITING;
			break;

		case WAITING:
			encoder2.pinState_A = digitalRead(encoder2.pin_A);
			if(encoder2.pinState_A != encoder2.pinStateOld_A)
			{
				encoder2.pinState_B = digitalRead(encoder2.pin_B);
				if(encoder2.pinState_A == encoder2.pinState_B)
					encoder2.data = 1;

				else
					encoder2.data = -1;

				encoder2.state = IDLE;
			}
			break;
	}
}
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

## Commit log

2014-10-30 All encoder test
2014-10-30 All encoder Test + 1 MS
2014-11-15 Add Scorbot 1 arm control and FZZ
    [3MiniPro1PCB.fzz]
2016-09-26 Scorbot Geekcon Work
    [3MiniPro1PCB.fzz, MEGA_ENC_MS.fzz, MEGA_oneDriver.fzz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]

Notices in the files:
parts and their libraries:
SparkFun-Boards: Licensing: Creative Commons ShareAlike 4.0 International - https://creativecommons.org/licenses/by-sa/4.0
